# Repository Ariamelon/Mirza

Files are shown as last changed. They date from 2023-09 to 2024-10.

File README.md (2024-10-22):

# Mirza
Current-feedback headphone amplifier module

## Disclaimer
This amplifier is licensed under CERN-OHL-S-2.0.

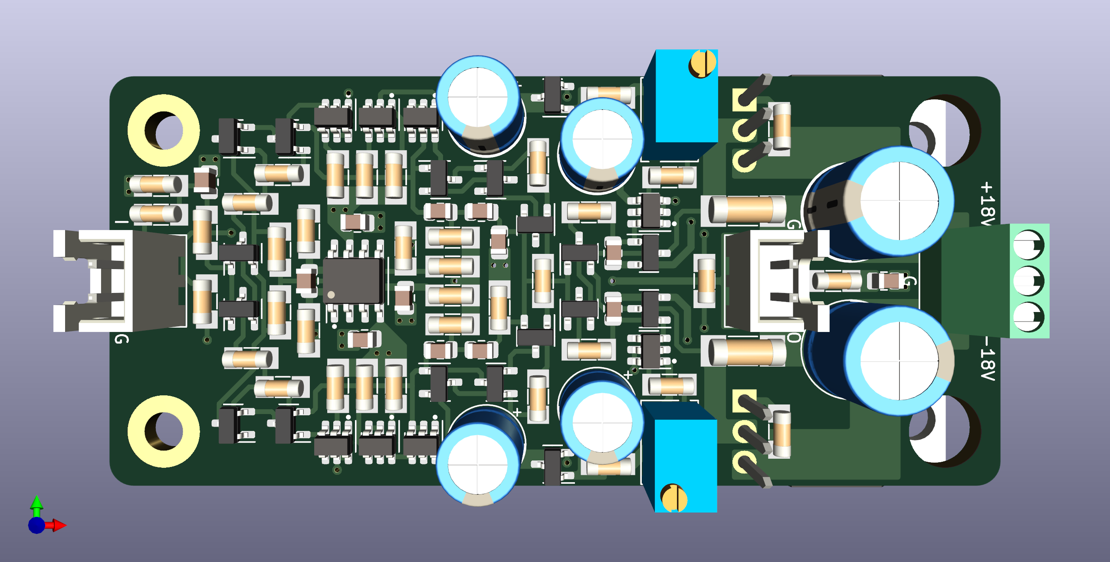
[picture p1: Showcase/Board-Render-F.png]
Board Render Front

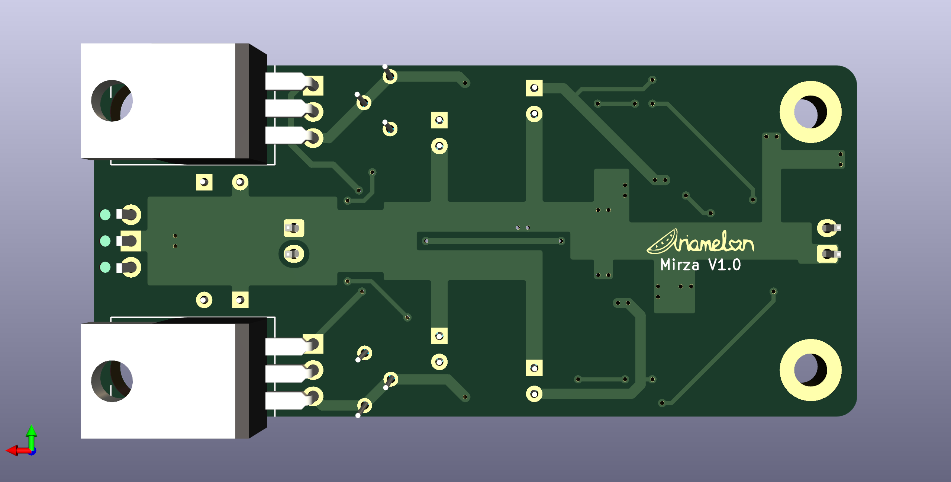
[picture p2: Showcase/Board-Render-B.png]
Board Render Back


## Changelog
* 22/10/2024: License updated to CERN-OHL-S-2.0.
* 05/10/2023: Changed input voltage to 15V.
* 28/09/2023: Changed size of emitter resistors to MELF0207 for better heat dissipation.
* 24/09/2023: Increased thickness of power traces. Updated footprints for SOT-23-3 and SOT-23-6 footprints.
* 23/09/2023: Changed all dual transistors to BCM847DS/BCM857DS for easier soldering.
* 22/09/2023: Changed power connector to phoenix terminal block.
* 20/09/2023: Shortened board by removing one pair of capacitors and increasing the size of the other and reducing the number of emitter resistors.
* 18/09/2023: Changed power header to JST XH 6-pin.
* 17/09/2023: Repositioning of parts. Added interactive BOM. Changed some values. Removed PTC fuses. Lengthened board to add JST XH connectors.
* 16/09/2023: Initial public upload.

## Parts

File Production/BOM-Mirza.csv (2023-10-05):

Comment | Designator | Footprint | LCSC
1u | C14,C15,C18,C19 | C_0805_2012Metric | C126592
ADA4522-1 | U1 | SOIC-8_3.9x4.9mm_P1.27mm | C160794
10n | C13 | C_0805_2012Metric | C161250
47p | C2,C3 | C_0805_2012Metric | C162302
470u | C16,C17 | CP_Radial_D8.0mm_P3.50mm | C178717
2k2 | R1,R15,R16,R22,R23 | R_MiniMELF_MMA-0204 | C1884620
560 | R10,R42,R5 | R_MiniMELF_MMA-0204 | C1884632
150 | R43 | R_MiniMELF_MMA-0204 | C2074241
220 | R18,R20,R26,R29,R30,R31 | R_MiniMELF_MMA-0204 | C2074282
0R47 | R36,R37 | R_MELF_MMB-0207 | C2079987
10k | R2,R25,R33,R4 | R_MiniMELF_MMA-0204 | C2084764
68 | R11,R12,R13,R14,R17,R21,R27,R28,R3,R38,R6,R7,R8,R9 | R_MiniMELF_MMA-0204 | C2086951
100u | C6,C7,C8,C9 | CP_Radial_D6.3mm_P2.50mm | C264049
100k | R19,R32 | R_MiniMELF_MMA-0204 | C2836210
1M | R24,R40 | R_MiniMELF_MMA-0204 | C4339242
BCM847DS | Q11,Q12,Q2,Q22 | SOT-23-6 | C549558
BCM857DS | Q1,Q10,Q21,Q9 | SOT-23-6 | C549564
100p | C1,C10,C11,C12,C4,C5 | C_0805_2012Metric | C710961
1k | RV1,RV2 | Potentiometer_Bourns_3266W_Vertical | C780233
2SC3324 | Q5 | SOT-23-3
2SA1312 | Q3 | SOT-23-3
2SC3324 | Q18 | SOT-23-3
2SC3324 | Q19 | SOT-23-3
2SA1312 | Q16 | SOT-23-3
2SA1312 | Q15 | SOT-23-3
Out | J2 | JST_XH_B2B-XH-A_1x02_P2.50mm_Vertical
2SA1312 | Q23 | SOT-23-3
2SA1312 | Q26 | SOT-23-3
2SA1312 | Q8 | SOT-23-3
2SA1312 | Q7 | SOT-23-3
2SC3324 | Q6 | SOT-23-3
2SC3324 | Q4 | SOT-23-3
2SC3324 | Q13 | SOT-23-3
2SA1312 | Q20 | SOT-23-3
Power | J3 | TerminalBlock_Phoenix_MPT-0,5-3-2.54_1x03_P2.54mm_Horizontal_MiddleGND
2SC3324 | Q17 | SOT-23-3
2SC3324 | Q24 | SOT-23-3
In | J1 | JST_XH_B2B-XH-A_1x02_P2.50mm_Vertical
2SA1312 | Q14 | SOT-23-3
2SC3324 | Q25 | SOT-23-3
D45H11 | Q27 | TO-220-3_Horizontal_TabUp
D44H11 | Q28 | TO-220-3_Horizontal_TabUp

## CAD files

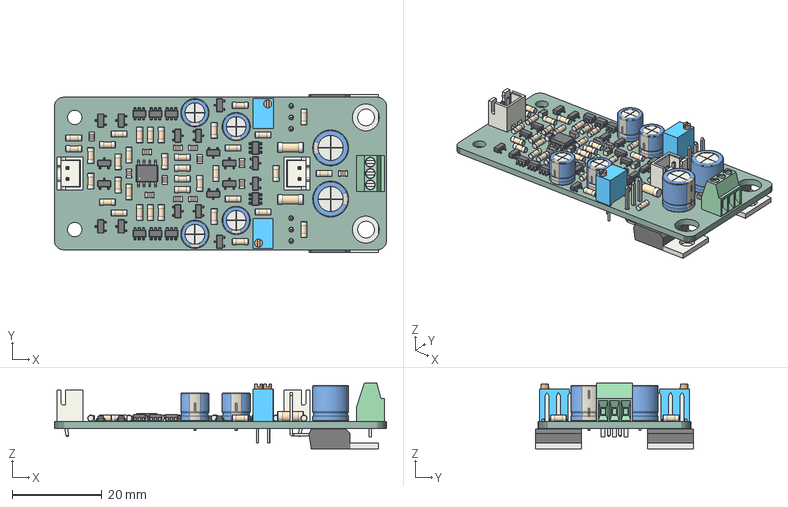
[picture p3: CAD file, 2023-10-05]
Showcase/Mirza-Board.step
74.0 x 35.2 x 14.6 mm
Mirza PCB

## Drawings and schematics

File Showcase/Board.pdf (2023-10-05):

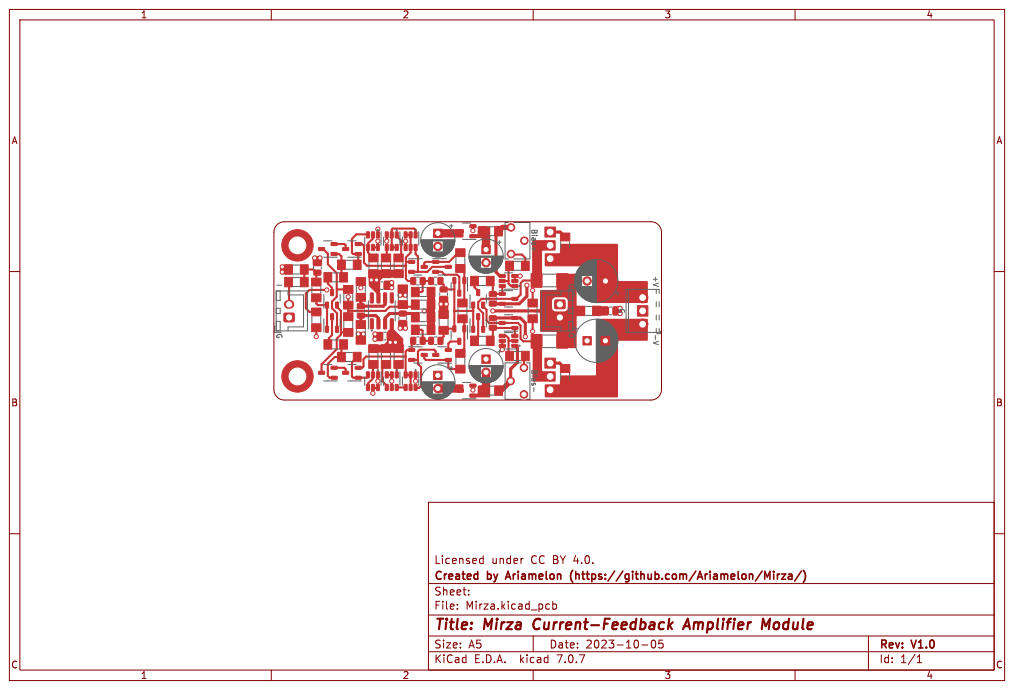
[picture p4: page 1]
O Bias- Bias+ G; G-V +VIG; BC Date: 2023-10-05 KiCad; kicad; 7.0.7 Size: A5; Rev: V1.0; Id: 1/1 Title: Mirza Current-Feedback; Amplifier Module; File:; Mirza.kicad_pcb Sheet: Created; by Ariamelon; (https://github.com/Ariamelon/Mirza/) Licensed; under CC

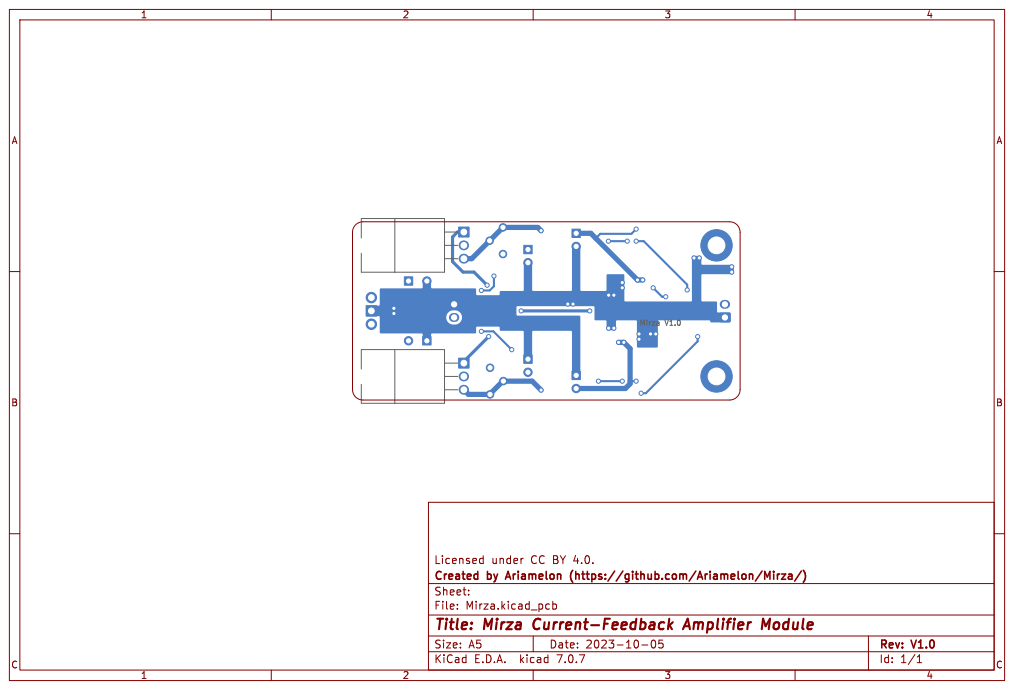
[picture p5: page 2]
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

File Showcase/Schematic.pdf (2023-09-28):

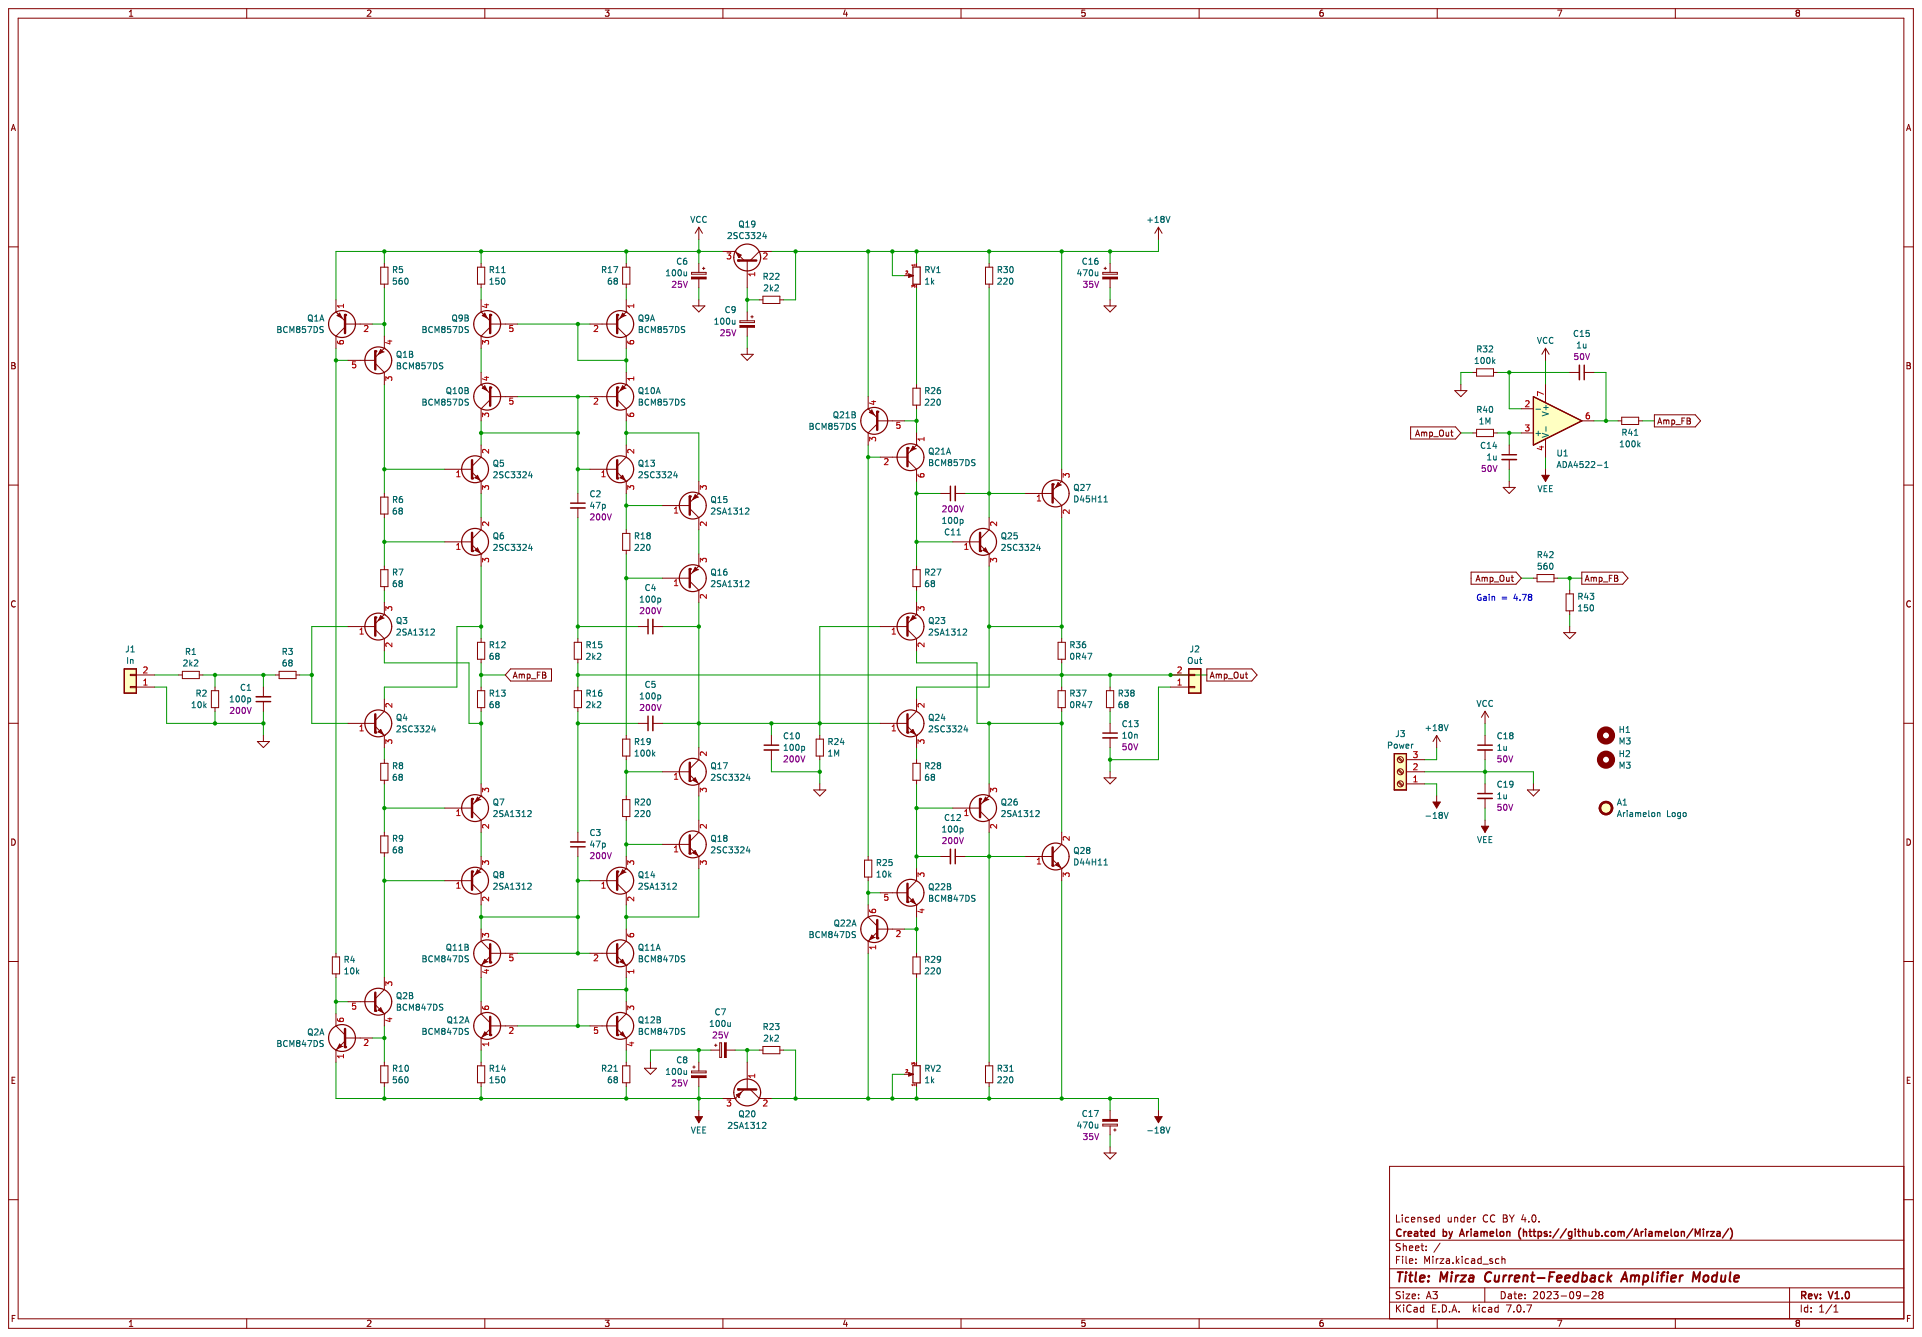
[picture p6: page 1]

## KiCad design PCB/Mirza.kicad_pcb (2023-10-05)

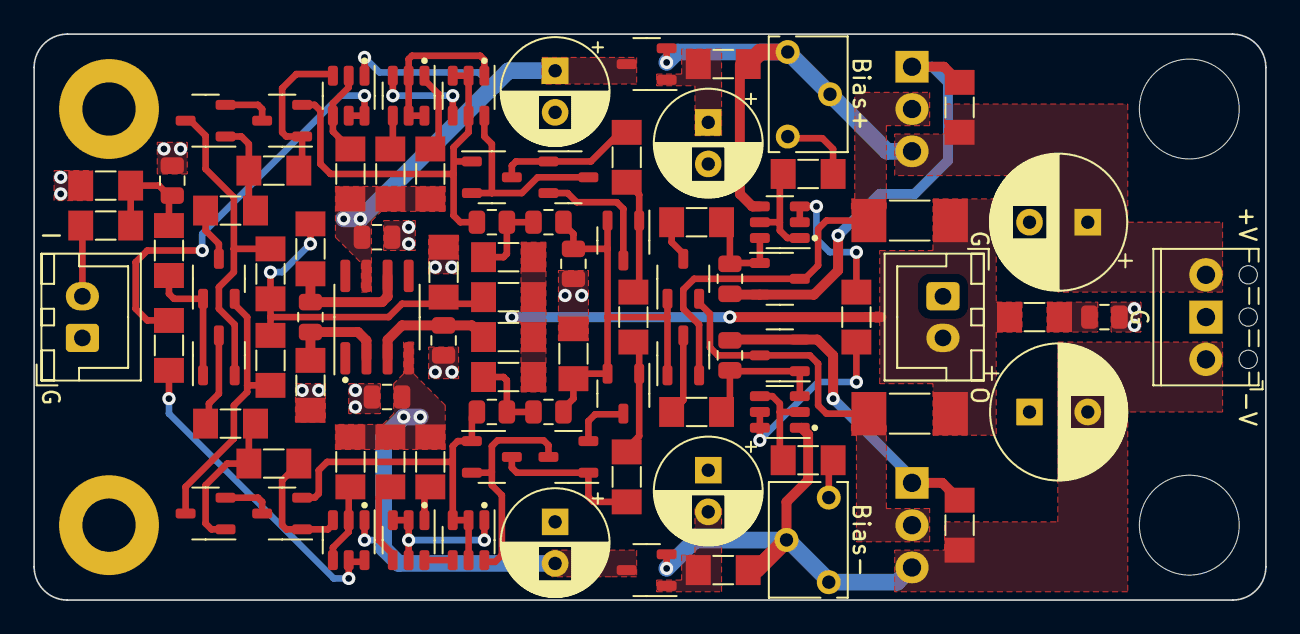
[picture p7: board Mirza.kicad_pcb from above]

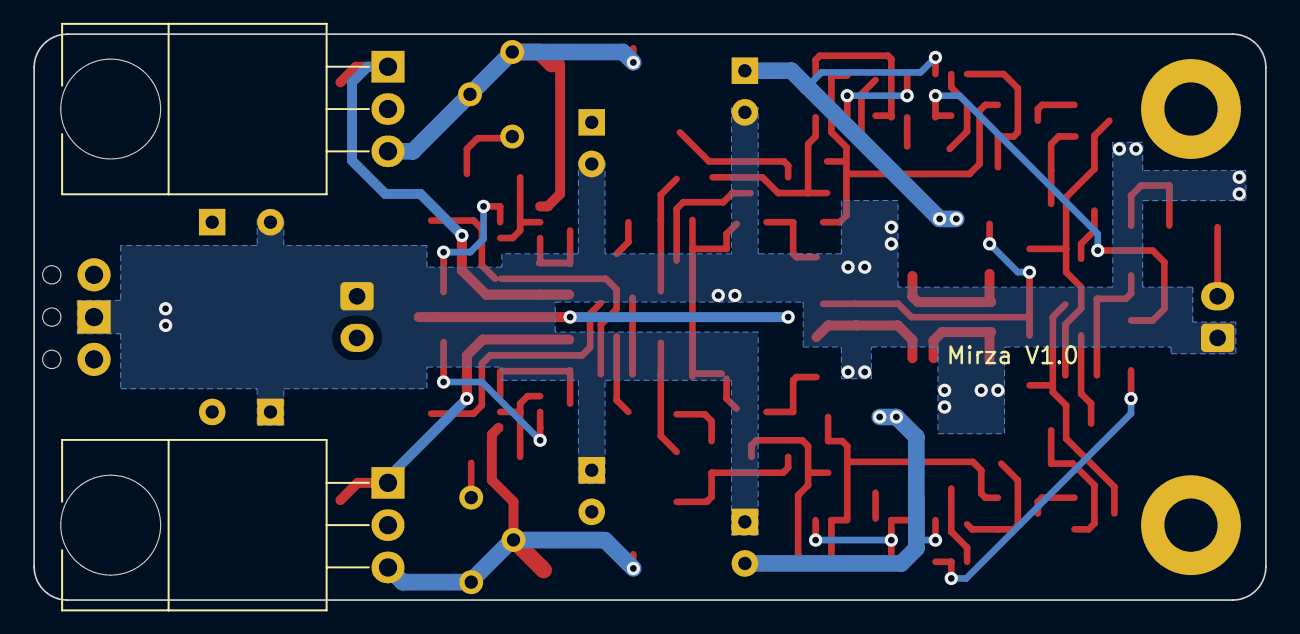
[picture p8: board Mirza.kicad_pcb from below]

Board: 2 copper layers, 74.0 x 34.0 mm, 95 parts (3 on the bottom side), 65 nets.

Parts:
A1: Ariamelon Logo; Ariamelon_Logo_Small_Mask
C1, C4, C5, C10, C11, C12: 100p; C_0805_2012Metric
C2, C3: 47p; C_0805_2012Metric
C6, C7, C8, C9: 100u; CP_Radial_D6.3mm_P2.50mm
C13: 10n; C_0805_2012Metric
C14, C15, C18, C19: 1u; C_0805_2012Metric
C16, C17: 470u; CP_Radial_D8.0mm_P3.50mm
H1, H2: M3; MountingHole_3.2mm_M3_Pad
J1: In; JST_XH_B2B-XH-A_1x02_P2.50mm_Vertical
J2: Out; JST_XH_B2B-XH-A_1x02_P2.50mm_Vertical
J3: Power; TerminalBlock_Phoenix_MPT-0,5-3-2.54_1x03_P2.54mm_Horizonta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
Q1, Q9, Q10, Q21: BCM857DS; SOT-23-6
Q2, Q11, Q12, Q22: BCM847DS; SOT-23-6
Q3, Q7, Q8, Q14, Q15, Q16, Q20, Q23, Q26: 2SA1312; SOT-23-3
Q4, Q5, Q6, Q13, Q17, Q18, Q19, Q24, Q25: 2SC3324; SOT-23-3
Q27: D45H11; TO-220-3_Horizontal_TabUp
Q28: D44H11; TO-220-3_Horizontal_TabUp
R1, R15, R16, R22, R23: 2k2; R_MiniMELF_MMA-0204
R2, R4, R25, R33: 10k; R_MiniMELF_MMA-0204
R3, R6, R7, R8, R9, R11, R12, R13, R14, R17, R21, R27, R28, R38: 68; R_MiniMELF_MMA-0204
R5, R10, R42: 560; R_MiniMELF_MMA-0204
R18, R20, R26, R29, R30, R31: 220; R_MiniMELF_MMA-0204
R19, R32: 100k; R_MiniMELF_MMA-0204
R24, R40: 1M; R_MiniMELF_MMA-0204
R36, R37: 0R47; R_MELF_MMB-0207
R43: 150; R_MiniMELF_MMA-0204
RV1, RV2: 1k; Potentiometer_Bourns_3266W_Vertical
U1: ADA4522-1; SOIC-8_3.9x4.9mm_P1.27mm

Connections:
+15V: C16.1, J3.3, Q19.2 (C), Q21.4 (E2), Q27.3 (E), R22.2, R30.2, RV1.1, RV1.2
-15V: C17.2, J3.1, Q20.2 (C), Q22.1 (E1), Q28.3 (E), R23.2, R31.2, RV2.1, RV2.2
Amp_FB: R12.2, R13.1, R33.1, R42.1, R43.2
Amp_Out: J2.2, R15.2, R16.2, R36.2, R37.2, R38.1, R40.2, R42.2
GND: C1.1, C6.2, C7.1, C8.1, C9.2, C10.2, C13.2, C14.2, C16.2, C17.1, C18.2, C19.1, J1.1, J2.1, J3.2, R2.2, R24.1, R32.2, R43.1
unnamed: C1.2, R1.2, R2.1, R3.1
unnamed: C2.2, C4.1, R15.1
unnamed: C3.2, C5.1, R16.1
unnamed: C13.1, R38.2
unnamed: C15.1, R33.2, U1.6
unnamed: J1.2, R1.1
unnamed: Q1.2 (B1), Q1.4 (E2), R5.1
unnamed: Q1.5 (B2), Q1.6 (C1), R4.1
unnamed: Q1.3 (C2), Q5.1 (B), R6.2
unnamed: Q2.2 (B1), Q2.4 (E2), R10.2
unnamed: Q2.5 (B2), Q2.6 (C1), R4.2
unnamed: Q2.3 (C2), Q8.1 (B), R9.2
unnamed: Q3.1 (B), Q4.1 (B), R3.2
unnamed: Q3.2 (C), Q7.3 (E), R13.2
unnamed: Q3.3 (E), R7.1
unnamed: Q4.2 (C), Q6.3 (E), R12.1
unnamed: Q4.3 (E), R8.1
unnamed: Q5.3 (E), Q6.2 (C)
unnamed: Q6.1 (B), R6.1, R7.2
unnamed: Q7.1 (B), R8.2, R9.1
unnamed: Q7.2 (C), Q8.3 (E)
unnamed: Q9.1 (E1), R17.2
unnamed: Q9.4 (E2), R11.1
unnamed: C2.1, Q5.2 (C), Q10.2 (B1), Q10.3 (C2), Q10.5 (B2), Q13.1 (B)
unnamed: Q10.6 (C1), Q13.2 (C), Q15.3 (E)
unnamed: Q9.2 (B1), Q9.5 (B2), Q9.6 (C1), Q10.1 (E1)
unnamed: Q9.3 (C2), Q10.4 (E2)
unnamed: C3.1, Q8.2 (C), Q11.2 (B1), Q11.3 (C2), Q11.5 (B2), Q14.1 (B)
unnamed: Q11.6 (C1), Q14.2 (C), Q18.3 (E)
unnamed: Q11.1 (E1), Q12.2 (B1), Q12.3 (C2), Q12.5 (B2)
unnamed: Q11.4 (E2), Q12.6 (C1)
unnamed: Q12.1 (E1), R14.2
unnamed: Q12.4 (E2), R21.2
unnamed: Q13.3 (E), Q15.1 (B), R18.1
unnamed: Q14.3 (E), Q18.1 (B), R20.2
unnamed: Q15.2 (C), Q16.3 (E)
unnamed: Q16.1 (B), R18.2, R19.1
unnamed: C4.2, C5.2, C10.1, Q16.2 (C), Q17.2 (C), Q23.1 (B), Q24.1 (B), R24.2
unnamed: Q17.1 (B), R19.2, R20.1
unnamed: Q17.3 (E), Q18.2 (C)
unnamed: C9.1, Q19.1 (B), R22.1
unnamed: C7.2, Q20.1 (B), R23.1
unnamed: Q21.2 (B1), Q21.3 (C2), R25.1
unnamed: C11.1, Q21.6 (C1), Q25.1 (B), R27.2
unnamed: Q21.1 (E1), Q21.5 (B2), R26.1
unnamed: Q22.2 (B1), Q22.4 (E2), R29.1
unnamed: Q22.5 (B2), Q22.6 (C1), R25.2
unnamed: C12.2, Q22.3 (C2), Q26.1 (B), R28.2
unnamed: Q23.2 (C), Q26.3 (E), Q28.2 (C), R37.1
unnamed: Q23.3 (E), R27.1
unnamed: Q24.2 (C), Q25.3 (E), Q27.2 (C), R36.1
unnamed: Q24.3 (E), R28.1
unnamed: C11.2, Q25.2 (C), Q27.1 (B), R30.1
unnamed: C12.1, Q26.2 (C), Q28.1 (B), R31.1
unnamed: R26.2, RV1.3
unnamed: R29.2, RV2.3
unnamed: C14.1, R40.1, U1.3 (+)
unnamed: C15.2, R32.1, U1.2 (-)
VCC: C6.1, C18.1, Q1.1 (E1), Q19.3 (E), R5.2, R11.2, R17.1, U1.7 (V+)
VEE: C8.2, C19.2, Q2.1 (E1), Q20.3 (E), R10.1, R14.1, R21.1, U1.4 (V-)

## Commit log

2023-09-14 Completed layout
    [Amp.kicad_sch, DC_Protection.kicad_sch, Mirza.kicad_pcb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]
2023-09-14 Update Ariamelon-Kicad-Master-Library
2023-09-16 Rearranged and rerouted board
    [Mirza.kicad_pcb, Mirza.kicad_sch]
2023-09-16 Initial public upload
    [BOM-Mirza.csv, DIY BOM.csv, Mirza.kicad_pcb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]
2023-09-17 17/09/2023 update
    Repositioning of parts. Added interactive BOM. Changed some values. Removed PTC fuses. Lengthened board to add JST XH connectors.
    [BOM-Mirza.csv, DIY BOM.csv, Mirza.kicad_pcb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]
2023-09-18 18/09/2023 update
    Changed power header to JST XH 6-pin.
    [BOM-Mirza.csv, Mirza.kicad_pcb, Mirza.kicad_sch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]
2023-09-20 20/09/2023 update
    Shortened board by removing one pair of capacitors and increasing the size of the other and reducing the number of emitter resistors.
    [BOM-Mirza.csv, Mirza.kicad_pcb, Mirza.kicad_sch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]
2023-09-22 22/03/2023 update
    Changed power connector to phoenix terminal block.
    [BOM-Mirza.csv, Mirza.kicad_pcb, Mirza.kicad_sch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]
2023-09-23 23/09/2023 update
    Changed all dual transistors to BCM847DS/BCM857DS for easier soldering.
    [BOM-Mirza.csv, Mirza.kicad_pcb, Mirza.kicad_sch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]
2023-09-24 24/09/2023 update
    Increased thickness of power traces. Updated footprints for SOT-23-3 and SOT-23-6 footprints.
    [BOM-Mirza.csv, Mirza.kicad_pcb, Mirza.kicad_sch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]
2023-09-28 28/09/2023 update
    Changed size of emitter resistors to MELF0207 for better heat dissipation.
    [BOM-Mirza.csv, Mirza.kicad_pcb, Mirza.kicad_sch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]
2023-10-05 05/10/2023 update
    Changed input voltage to 15V.
    [BOM-Mirza.csv, Mirza-Board.step, Mirza.kicad_pcb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]

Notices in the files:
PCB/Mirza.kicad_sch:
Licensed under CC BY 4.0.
